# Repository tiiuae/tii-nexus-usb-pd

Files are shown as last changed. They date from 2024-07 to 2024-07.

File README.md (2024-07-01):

# TII Nexus USB PD

A small tri-input, single output board that gives you redundant power at USB-PD 2.0 voltages.
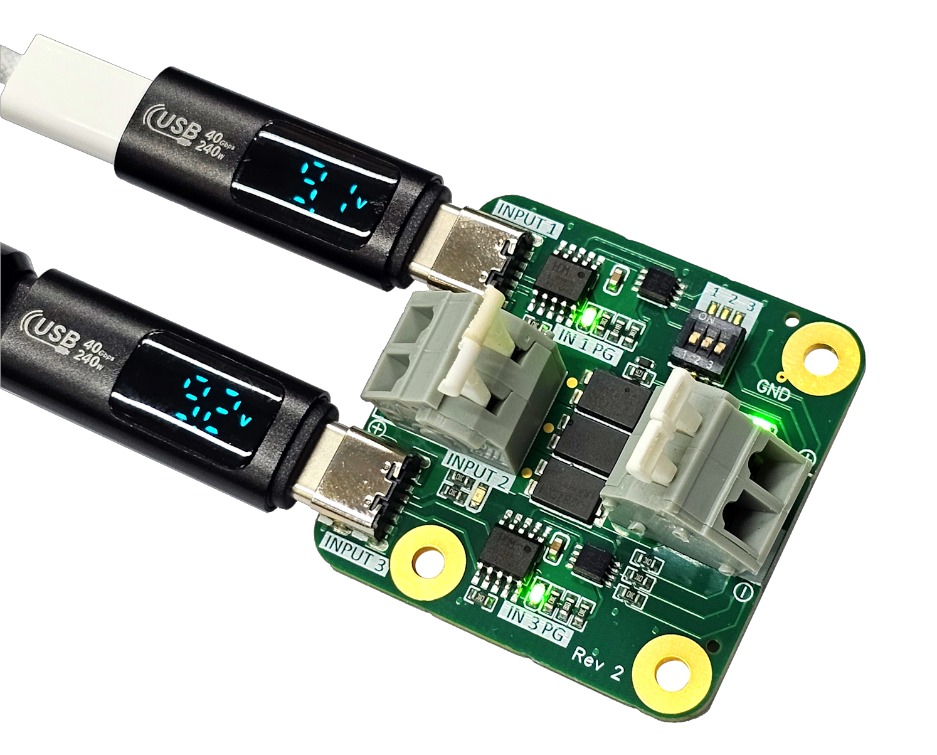
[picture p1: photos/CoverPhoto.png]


This project came to be when we realized that a lot of our experiments require both portability and/or redundancy, and while USB-PD powerbanks are highly available on the market, we had a problem with swapping them out without powering down the system. 

Even powerbanks that support power output while charging may go offline for some small amount of time when plugged in, which was unacceptable in our scenario. With this board, a second powerbank or generic power supply can be connected to allow the removal of a nearly depleted powerbank. This allow allows for multiple voltage sources to be used to ensure redundancy, and has the advantage of being non-proprietary.

## Specifications
Voltage output with USB input: 5, 9, 12, 15, or 20V

Voltage input/output with Terminal input: 0 - 40V

Current: 0-2A (up-to 5A possible with additional heatsinking)

Due to the use of Schottky diodes, the highest voltage input will be seen at the input minus 0-0.35 V and load sharing is unlikely unless power sources are well matched. The two USB-C inputs work by communicating over CC lines to the CH224K chips which act as decoys and negotiate the selected voltage. When the negotiation is successful, a "Power Good" or "PG" LED lights up to inform the user that the correct voltage is applied to the output.

## Case
A case design is also included in this repository, it is designed to be made by a Nylon SLS 3D printer or a similar high resolution printing technology.

Included on the case is a place where you can mark the set voltage, use a thin object with paint or ink to mark the correct segments, or modify the 3D model if the desired voltage is known.
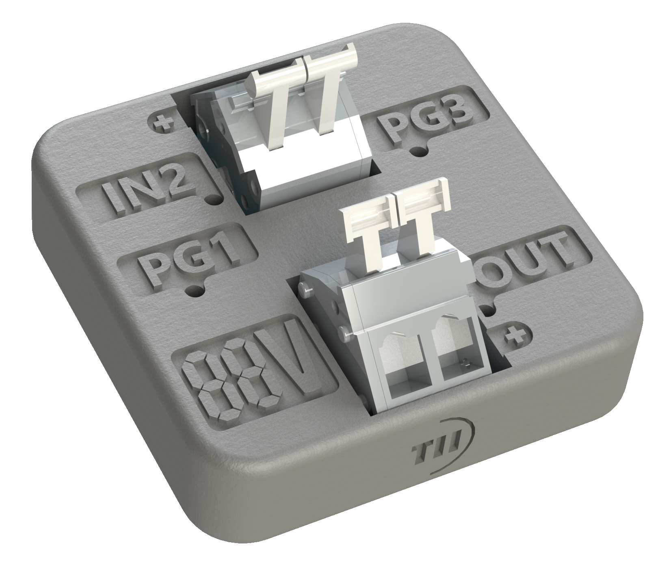
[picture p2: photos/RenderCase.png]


## Make it
You can use the Gerber files attached in this repository, or import the EasyEDA project included in the PCB folder. If you use JLCPCB or any other PCB service that also offers 3D printing, you can order the case along with the PCB.

## Use it
To use this board, you can plug between one and three inputs: The two type C ports and the terminal in between. The output voltage will be the highest of the three input voltage minus a 0 - 0.35 V diode drop. After selecting the correct setting on the DIP switch for the desired output voltage (as shown in the table below), you can plug in a USB C input and check for its respective "PG" LED. 

For example, if you plug a cable into input 1 and the LED that is labeled "IN 1 PG" turns ON, this means that the requested voltage is successfully negotiated and is being delivered. However, if that LED is OFF, the desired voltage is not being delivered by the type C cable. This may be because the power supply connected to the cable is not capable of delivering the desired voltage, or the power supply is not powered. Some power supplies may support some voltages and not others, for example some laptop type C power supplies may be able to deliver 5 V, 9 V, or 20 V, so if 15 V is requested you will not get that, and the LED will be OFF. 

One example is shown below, where 15 V is requested but only one of the two power supplies is capable of delivering that voltage, note the state of the PG LEDs.
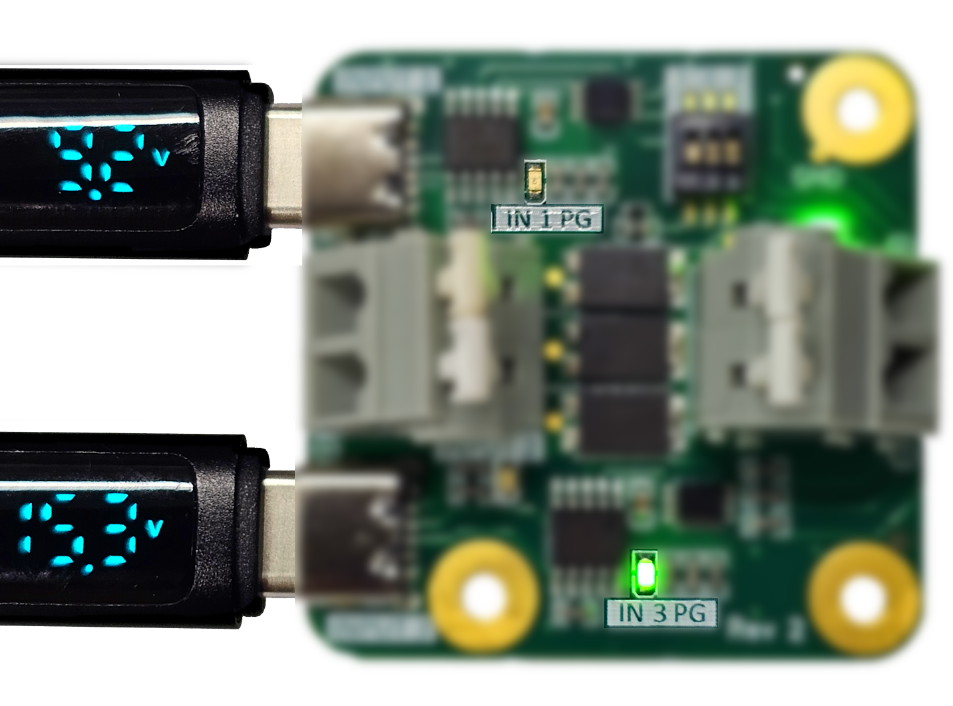
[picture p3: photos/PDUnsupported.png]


If both "PG" LEDs are ON, removing one input will not affect the output. A very small voltage change may be observable due to power supplies providing a slightly different voltage level, but the current flow will be constant. Due to this natural slight difference in voltage between multiple sources, the power is not shared between inputs - only one input is used in most cases. If both LEDs are ON and a higher voltage is applied on input 2, the output voltage will go up from that which is selected from the USB ports to equal that of input 2 minus the diode drop.

You can use the output terminal block to power your desired circuit. Simply press down on white levers to lift the springs, insert your wires, and let go of the levers.

To select a voltage level, follow this table. Where a 0 means putting that respective switch to "off", 1 means putting that switch to "on", and x means that the state of this switch does not matter in this case.
| Voltage | Pin 1 | Pin 2 | Pin 3 |
|---|---|---|---|
| 5 | 1 | X | X |
| 9 | 0 | 0 | 0 |
| 12 | 0 | 0 | 1 |
| 15 | 0 | 1 | 1 |
| 20 | 0 | 1 | 0 |

At around 40 x 34 mm for the board (without the case), this is a small way to add redundancy to your system.

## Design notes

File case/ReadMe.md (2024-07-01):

Files are made to be printed in SLS nylon for the Formlabs Fuse 1 printer. Tolerances may need to adjusted for other printers.

You will also need three M3 nuts and flat head M3 screws between 7-9 mm long (10mm will work if not tightened).

The intention behind the 7-segment caracters beside the output is to write down the selected PD voltage. Use whiteout for a dark material, or a marker for a lighter material. You can also use a chisel to remove the other segments, or remove them from the 3D model.


You can preview the case by clicking on the STL files included in this folder and using the GitHub integrated viewer. Click on the below image to open the file.

<div align="center"> 
  
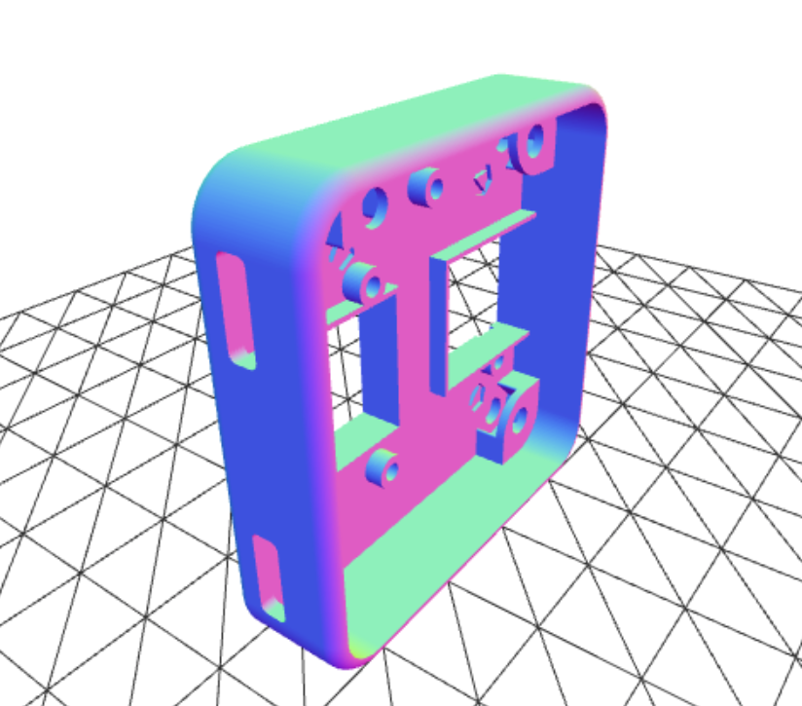
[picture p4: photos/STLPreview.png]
STL Preview
   
  
</div>

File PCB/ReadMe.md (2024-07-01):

We ordered this board from JLCPCB.com with the following options:
- Stack-up: 4 layer JLC04161H-7628
- Thickness: 1.6 mm
- Via covering: Epoxy filled and capped
- Surface finish: ENIG
- Min via hole/size: 0.3/0.4mm
- Remove order number: Yes

Green solder mask was used to be eligible for Economic PCBA.

To manually assemble the board, you can use the BOM and EasyEDA. The gerber files are included in PDF format as well.
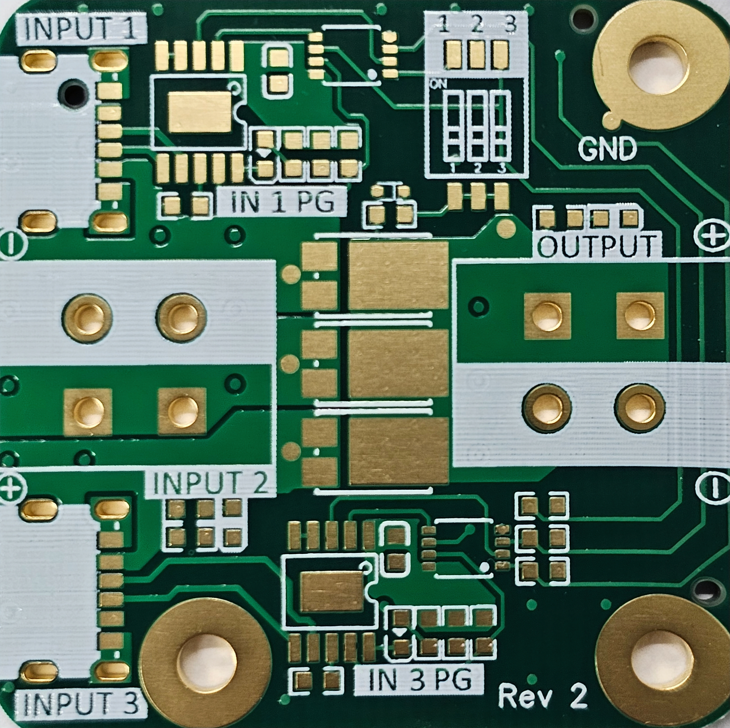
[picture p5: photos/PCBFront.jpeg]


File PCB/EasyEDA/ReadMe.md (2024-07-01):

These files contain the original design files on EasyEDA STD, facilitating easy modification and one click ordering from JLCPCB. An untested, smaller version of the PCB is also included. It used a barrel jack placed at a 90 degree angle. The following are the original instructions included by EasyEDA.

How to use：

At editor, open the document via: Top menu - File - Open - EasyEDA... , and select the json file, then open it at the editor, you can save it into a project.

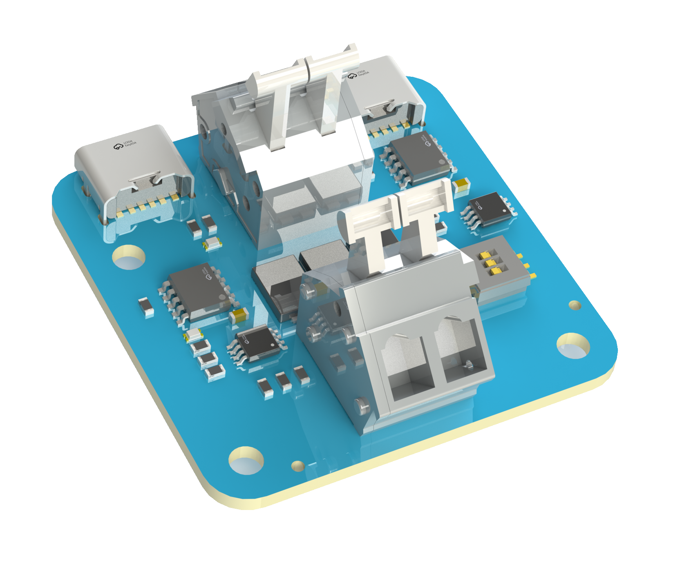
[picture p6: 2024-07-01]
photos/Render.png

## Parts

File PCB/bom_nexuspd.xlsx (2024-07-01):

ID | Name | Designator | Footprint | Quantity | Manufacturer Part | Manufacturer | Supplier | Supplier Part | Price | 3DModel | link
1 | pad | GND,TP5,TP1,TP2,TP4 | TEST_TESTPOINT | 5
2 | TYPE-C 6P(073) | J_IN1,J_IN3 | TYPE-C-SMD_TYPE-C-6P | 2 | TYPE-C 6P(073) | SHOU HAN(首韩) | LCSC | C668623 | 0.039 | TYPE-C-SMD_6P-L8.9-W6.8-H3.2-P1.00 | https://item.szlcsc.com/458819.html
3 | XY115A-5.0-2P | J_IN2,J_OUT | CONN-TH_XY115A-5.0-2P | 2 | XY115A-5.0-2P | Ningbo Xinlaiya Elec. | LCSC | C784935 | 0.232 | CONN-TH_XY115A-5.0-2P | https://item.szlcsc.com/841143.html?ref=editor&logined=true
4 | 10kΩ | R12,R9,R10,R1,R3,R4,R5,R6,R8,R13,R16,R17 | R0603 | 12 | 0603WAF1002T5E | UNI-ROYAL(厚声) | LCSC | C25804 | 0.001 | R0603 | https://www.mouser.in/datasheet/2/447/PYu_RT_1_to_0_01_RoHS_L_11-1669912.pdf
5 | LM5Z3V3T1G | D4 | SOD-523F_L1.2-W0.8-LS1.7-RD | 1 | LM5Z3V3T1G | LRC(乐山无线电) | LCSC | C131795 | 0.02 | SOD-523F_L1.2-W0.8-H0.6-LS1.6 | https://item.szlcsc.com/235389.html
6 | 470Ω | R11 | R0603 | 1 | 0603WAF4700T5E | UNI-ROYAL(厚声) | LCSC | C23179 | 0.001 | R0603 | https://www.mouser.in/datasheet/2/447/PYu_RT_1_to_0_01_RoHS_L_11-1669912.pdf
7 | SN74LVC3G34DCTR | U3,U4 | MSOP-8_L2.9-W2.8-P0.65-LS4.0-BR | 2 |  |  |  | C139356 | 0.269 | MSOP-8_L3.0-W3.0-H1.1-LS4.9-P0.65 | https://item.szlcsc.com/112934.html
8 | 1uF | C1,C2 | C0603 | 2 | CL10A105KB8NNNC | SAMSUNG(三星) | LCSC | C15849 | 0.005 | C0603_L1.6-W0.8-H0.8 | https://item.szlcsc.com/362304.html
9 | SVM1550UB | D1,D2,D3 | TO-277B_3P-L6.1-W4.3-LS7.0-BR-1 | 3 | SVM1550UB_R2_00001 | PANJIT(强茂) | LCSC | C138358 | 0.441 | TO-277B_3P-L6.1-W4.3-LS7.0-BR-1 | https://atta.szlcsc.com/upload/public/pdf/source/20191009/99B8BBF6E1834CE289CA1D53FD0588E3_EC63EE4BEF5596D3FAE4DB0812345171.pdf
10 | C72043 | LED1,LED2,LED3,LED4 | LED0603-RD | 4 | 19-217/GHC-YR1S2/3T | EVERLIGHT(亿光) | LCSC | C72043 | 0.027 | LED0603-RD | https://item.szlcsc.com/347874.html
11 | 1kΩ | R2,R7 | R0603 | 2 | 0603WAF1001T5E | UNI-ROYAL(厚声) | LCSC | C21190 | 0.001 | R0603 | https://www.mouser.in/datasheet/2/447/PYu_RT_1_to_0_01_RoHS_L_11-1669912.pdf
12 | SHP-03 | SW1 | SW-SMD_SHP-03 | 1 | SHP-03 | Cha(昭华) | LCSC | C360672 | 0.546 | SW-SMD_SHP-03 | https://item.szlcsc.com/335625.html
13 | CH224K | U1,U2 | ESSOP-10_L4.9-W3.9-P1.0-LS6.0-TL-EP | 2 | CH224K | WCH(南京沁恒) | LCSC | C970725 | 0.512 | ESSOP-10_L4.9-W3.9-P1.0-LS6.0-TL-EP | https://atta.szlcsc.com/upload/public/pdf/source/20220425/5F3B4646B9AC793D88468BCB08421765.pdf

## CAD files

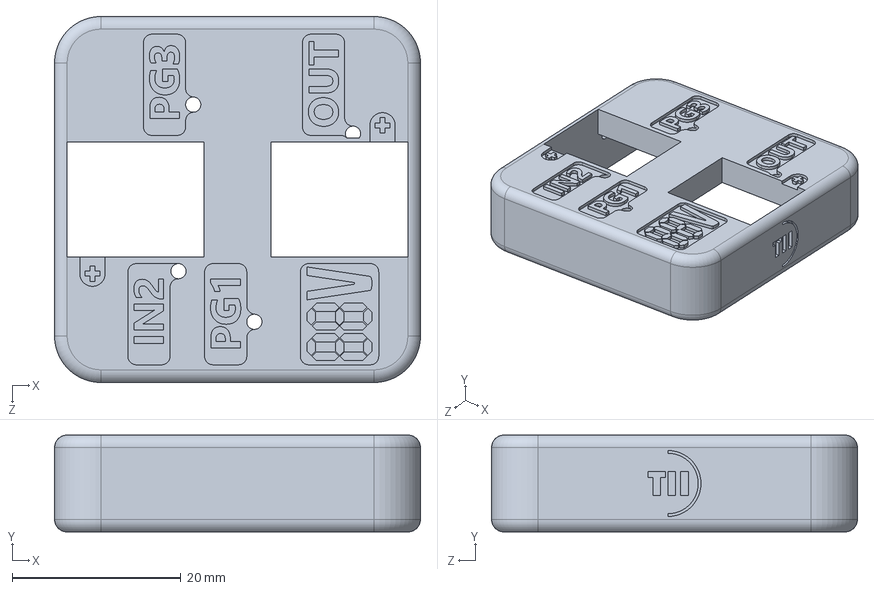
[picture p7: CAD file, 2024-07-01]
case/NexusCaseTop.STEP
43.4 x 11.5 x 43.4 mm

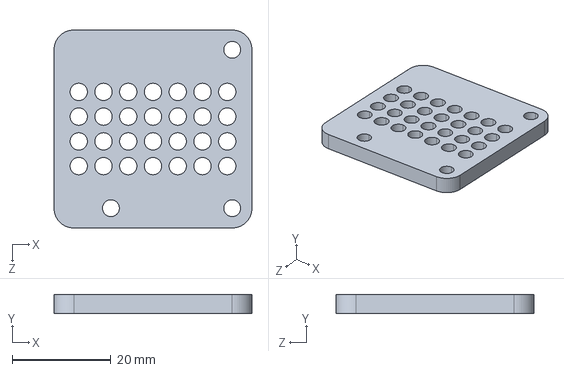
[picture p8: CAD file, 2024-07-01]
case/NexusCaseBottom.STEP
40.0 x 3.85 x 40.0 mm

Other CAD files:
case/NexusCaseBottom.3MF
case/NexusCaseBottom.SLDPRT
case/NexusCaseBottom.STL
case/NexusCaseTop.3MF
case/NexusCaseTop.SLDPRT
case/NexusCaseTop.STL

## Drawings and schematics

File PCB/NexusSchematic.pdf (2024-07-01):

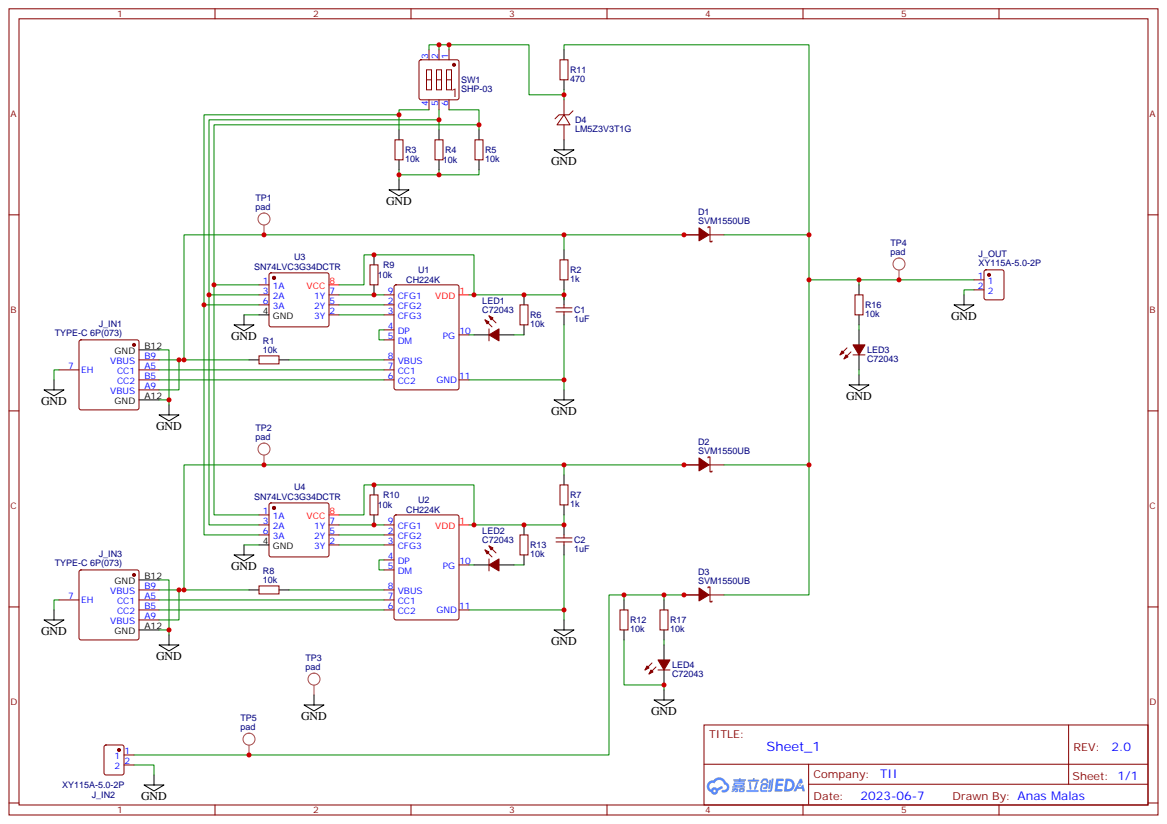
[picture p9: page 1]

Drawn By: Anas Malas
